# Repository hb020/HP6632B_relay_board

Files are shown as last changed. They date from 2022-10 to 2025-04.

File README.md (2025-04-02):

HP 66332A and HP 6632B-6634B #760 Relay Option Board
===================
This repository contains the schematics for a PCB to mount a relay board in an HP 6632B (and siblings) power supply. It is an adaption of the original A6 PCB used in option #760 units.
This relay board allows 2 things:
- the use of these power supplies as a 4 quadrant "poor man's SMU" (but with relay glitches).
- to isolate the output. In some situations, like with a large capacitive load or a battery, it is possible to damage the PSU's crowbar circuit when switching the output off. This board allows the disconnection of the output terminals. 

It is not needed to recalibrate the device after installation, although it would not hurt.

Once installed, you will NOT see the option appear when requesting `*OPT?` via the control interface (RS232/GPIB) (at least not on firmware 1.03). You will now however be able to use the relay control options in the front panel menu (under Output), or via `OUTPout`, `OUTPut:RELay`, and `OUTPut:RELay:POLarity`.

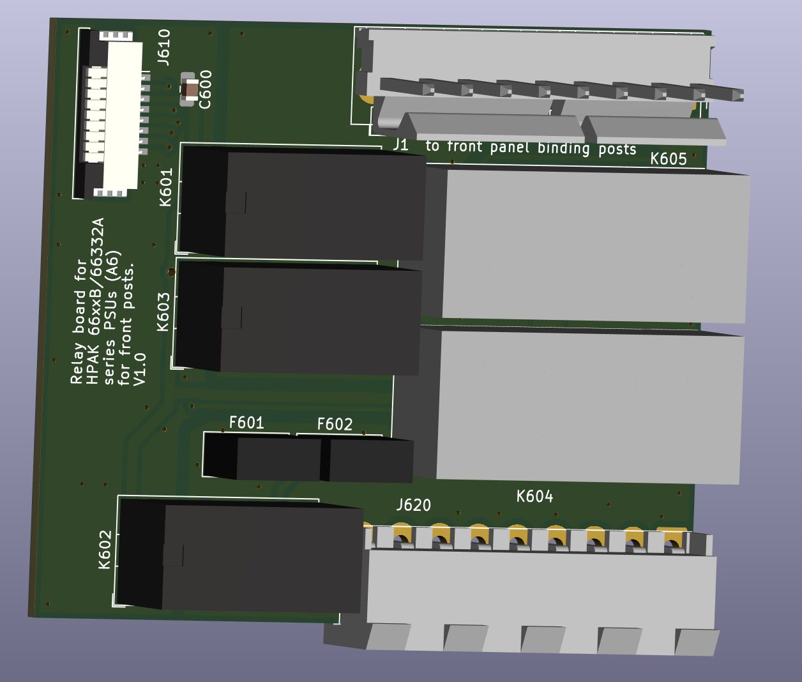
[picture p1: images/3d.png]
Circuit board


In contrast to the original option #760 PCB, this board:
- is meant to be used with front binding posts. See [option 020 board](https://github.com/hb020/HP6632B_binding_posts). If you want to use it with the standard backside terminals: just add 4 connections from the top connector to the bottom connector, according to the original schema that can be found in the service manual (the relevant extract can be found [here](doc/66332A%20Service%20Manual_9018-01125_extract.pdf)).
- has other minor changes like swapping the ports on the driver IC and allowing the use of standard series resistors (at least, the series that I had). 
- makes no use of the MP23/06612-00005 "Relay Option Bracket", which you will likely not have anyway if you do not already have the #760 board. The board is small enough and the weight distribution is such that this is not likely to be a problem.

For the component choice I took inspiration from "lukier" on [eevblog](https://www.eevblog.com/forum/repair/agilent-6632b-fault-repair-and-several-design-flaws/msg1019018/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). The main difference from his list was the FFC connectivity: 15cm is too short. I used molex 15267-0237: 20cm.

The components and layout chosen allow the board to be used on all variants of the HP 663xB family - even the 100 V 6634B.

The final result looks like this:
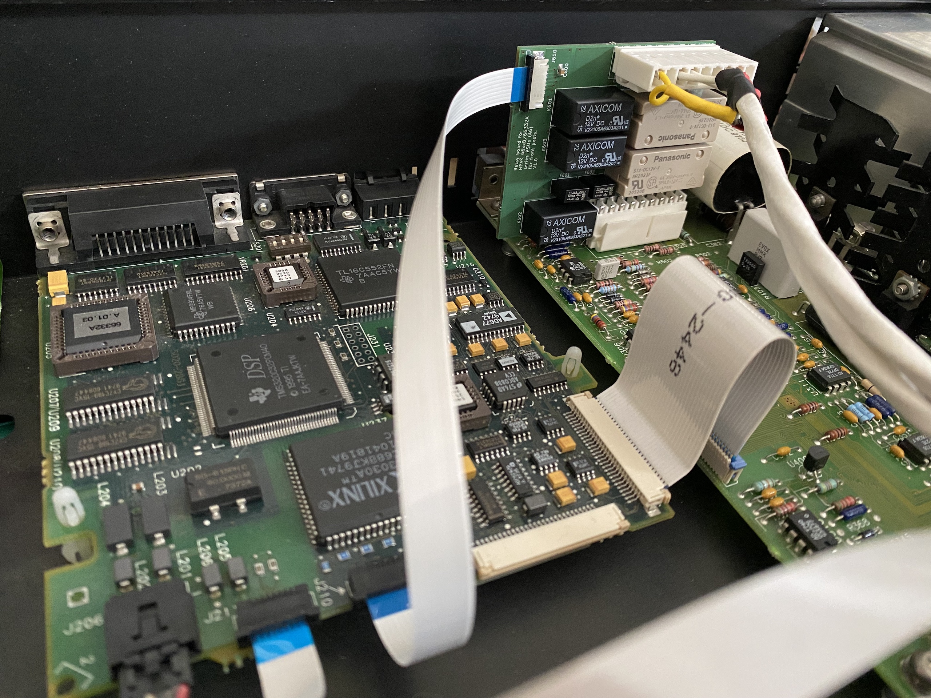
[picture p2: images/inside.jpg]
HP 66332A inside

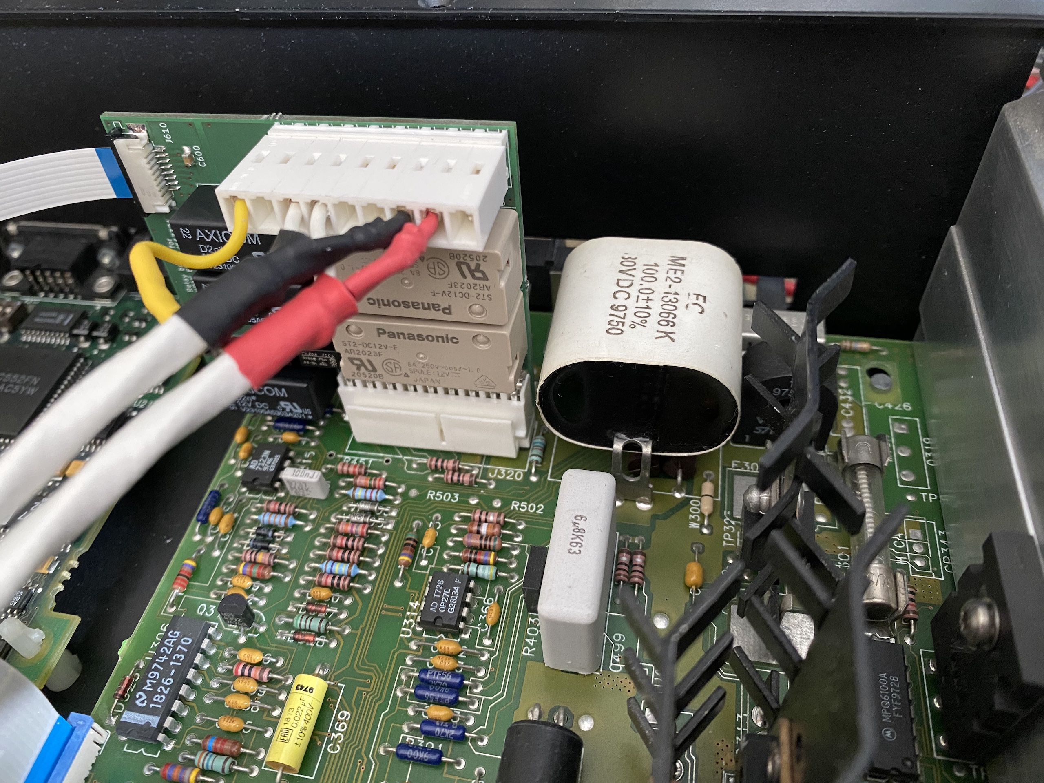
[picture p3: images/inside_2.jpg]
HP 66332A inside 2


Board behaviour
-----
This board keeps the sense lines functional, and I have not seen an impact on accuracy.
The sign of the voltage and current as measured (and set) does not change when you switch to "reverse" mode (the display still continues to show a positive voltage, although the voltage on the terminals is now negative).

During relay switching there are the inevitable delays and small artifacts.
Below is a switch from -1V (Reversed) to +1V (Normal), with a 1MΩ load. The switchover takes a little less than 80ms. 
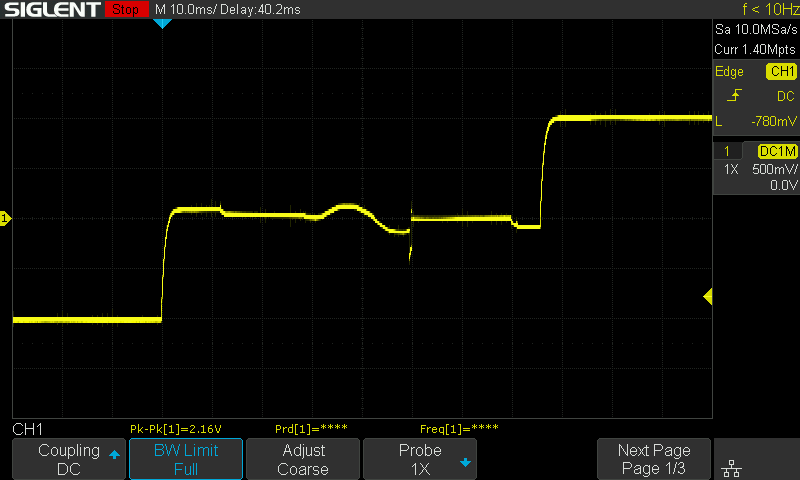
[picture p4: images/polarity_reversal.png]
polarity_reversal


The sine wave in the middle of the screen is 50Hz mains hum, as during that period the PSU output is disconnected. That hum, and the small spike that follows it, are largely suppressed when a load is applied.

About
-----
The root folder contains the KiCAD files. 
The gerber files can be found in the [/gerber](gerber/) folder.

Documentation of some of the components, and an extract of the service manual, with the original board drawings, can be found in the [/doc](doc/) folder. All files are publicly available on the respective manufacturers's websites, and are copied here for convenience. If this poses problems, let me know.

Related Repositories and info
--------------------

You may want to combine this with the [option 020 Frontpanel Binding Posts](https://github.com/hb020/HP6632B_binding_posts).

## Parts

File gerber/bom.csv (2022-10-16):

Designator | Footprint | Quantity | Value | LCSC Part #
C1, C600 | C_0805_2012Metric_Pad1.18x1.45mm_HandSolder | 2 | 100nF 25V
F601, F602 | Fuse_Littelfuse_395Series | 2 | Bussmann SS-5H-1.25A-APH
J1 | Molex_KK-396_A-41791-0009_1x09_P3.96mm_Vertical | 1 | Molex 26-60-4090 (KK396)
J610 | TE_84953-8_1x08-1MP_P1.0mm_Horizontal | 1 | 68610814422 8 pos 1mm FFC
J620 | Molex_KK-396_A-41815-0009_1x09_P3.96mm_Horizontal | 1 | Molex 09-48-1094 or 09-48-3095
K601, K602, K603 | Relay_DPDT_Omron_G5V-2 | 3 | V23105-A5303-A201
K604, K605 | Relay_Panasonic_ST2-F | 2 | ST2-DC12V-F
R1, R3, R5 | R_1206_3216Metric_Pad1.30x1.75mm_HandSolder | 3 | 75
R601, R602 | R_1206_3216Metric_Pad1.30x1.75mm_HandSolder | 2 | 220 0.5W
R603, R605, R607 | R_1206_3216Metric_Pad1.30x1.75mm_HandSolder | 3 | 100
R604, R606 | R_1206_3216Metric_Pad1.30x1.75mm_HandSolder | 2 | 150
U601 | SOIC-16_3.9x9.9mm_P1.27mm | 1 | NCV1413B

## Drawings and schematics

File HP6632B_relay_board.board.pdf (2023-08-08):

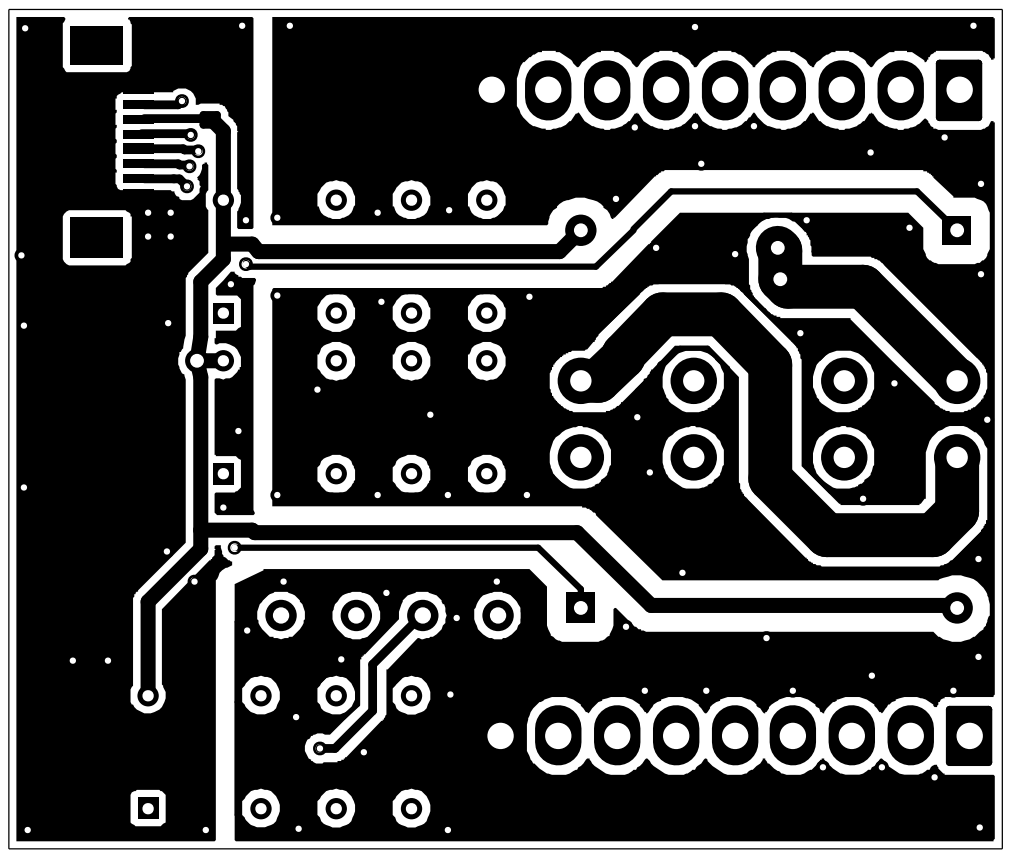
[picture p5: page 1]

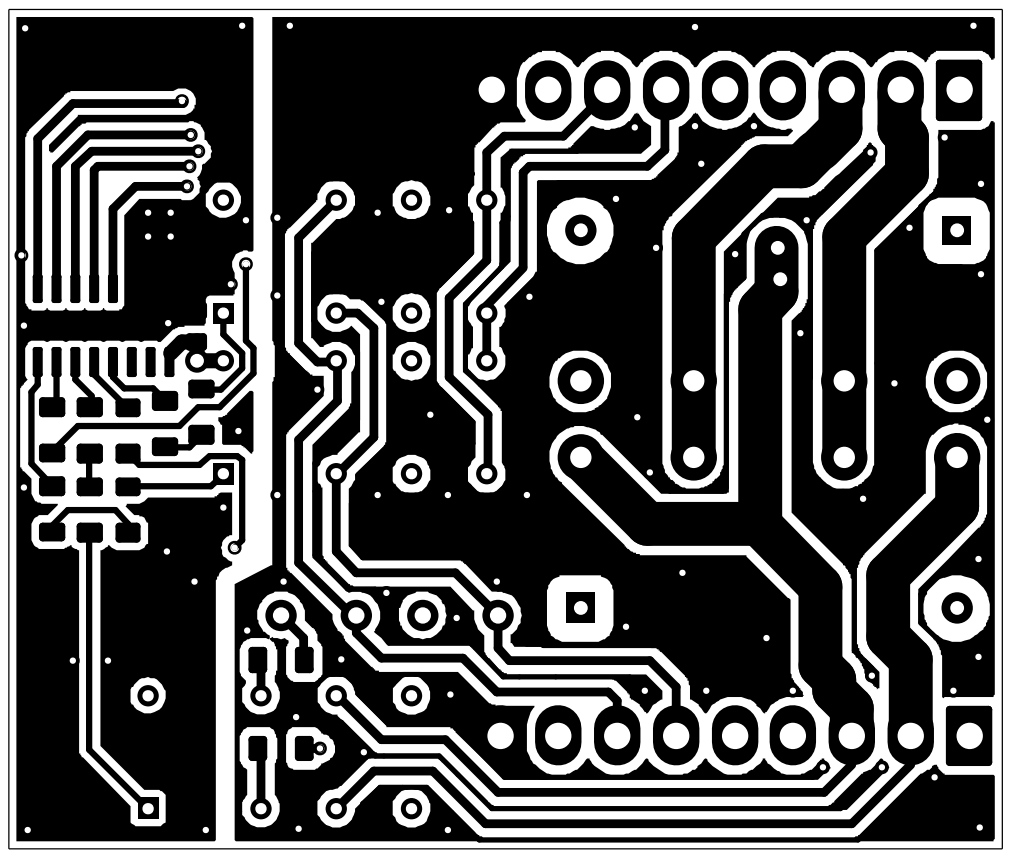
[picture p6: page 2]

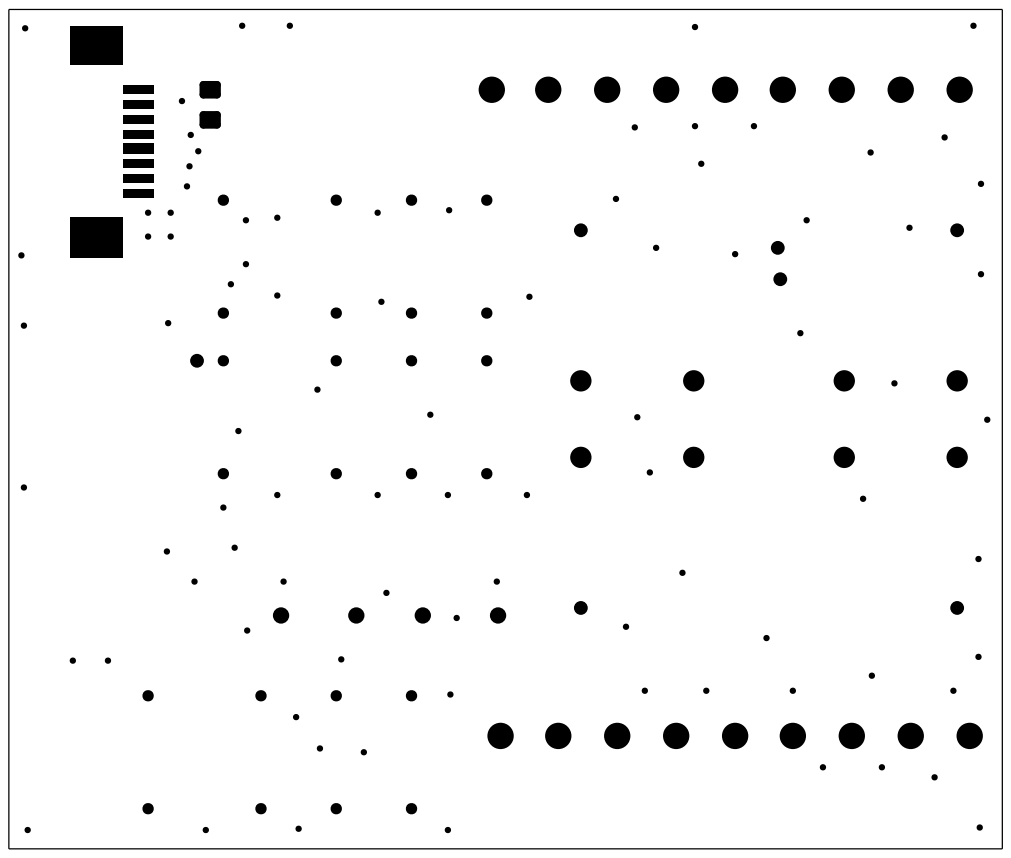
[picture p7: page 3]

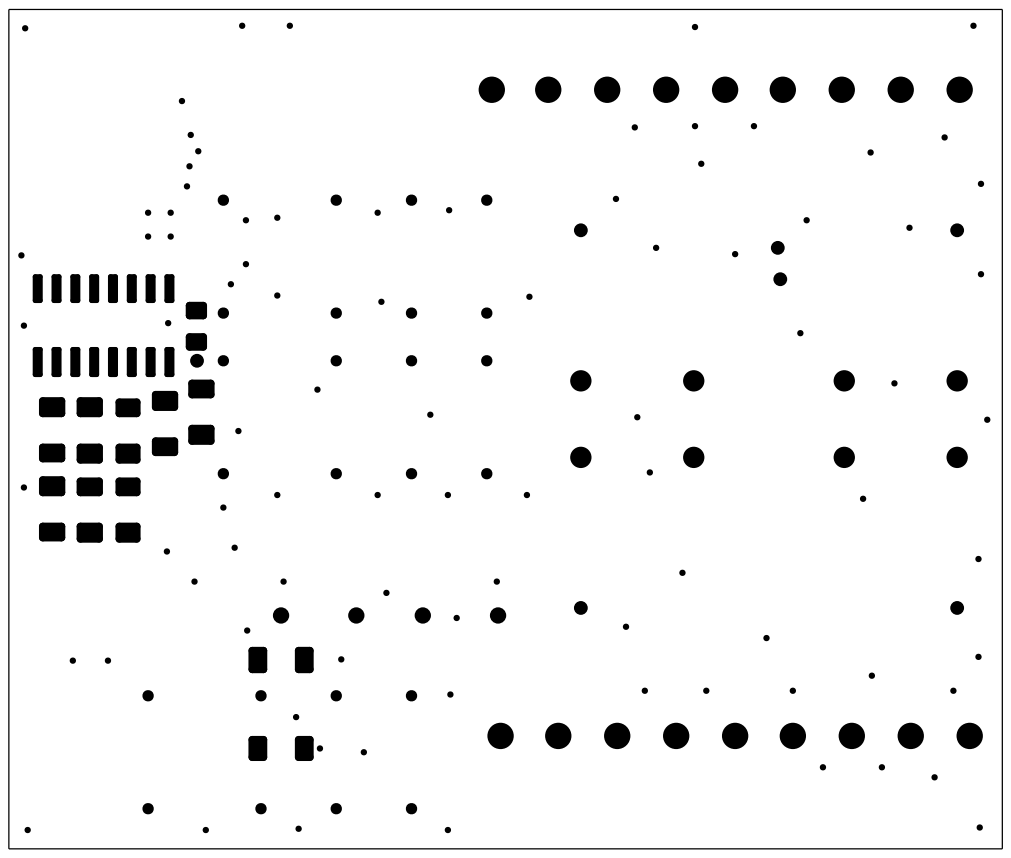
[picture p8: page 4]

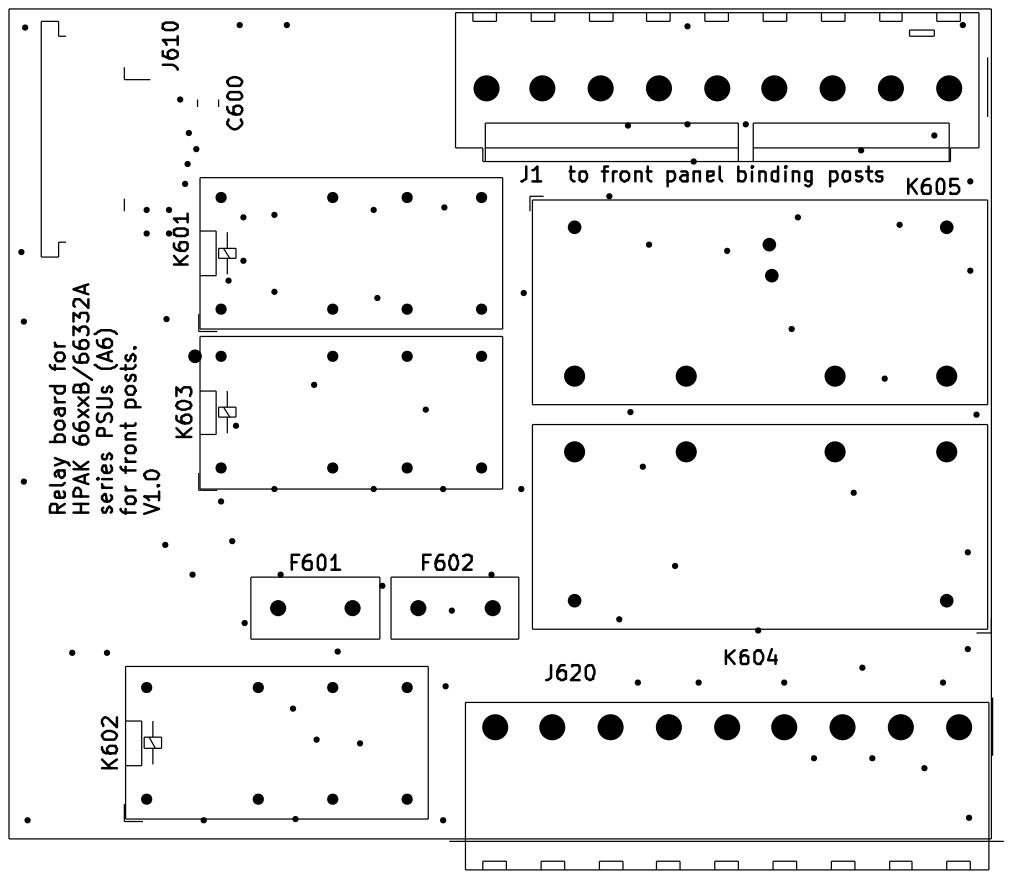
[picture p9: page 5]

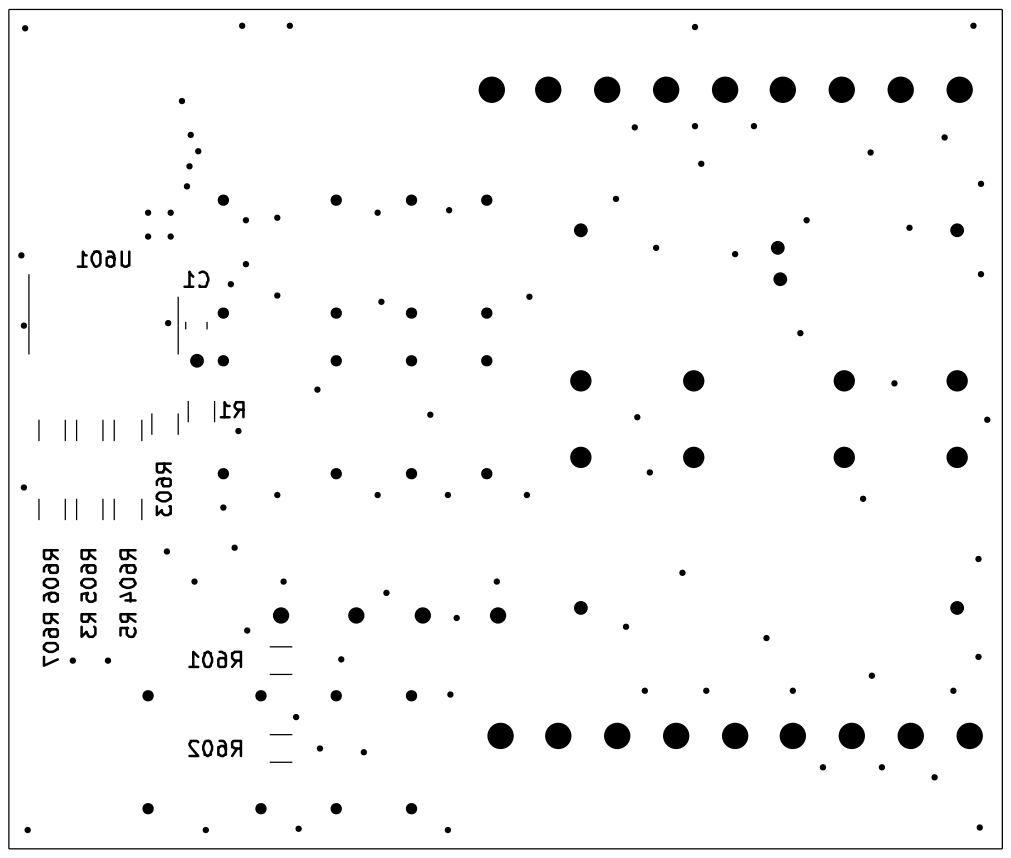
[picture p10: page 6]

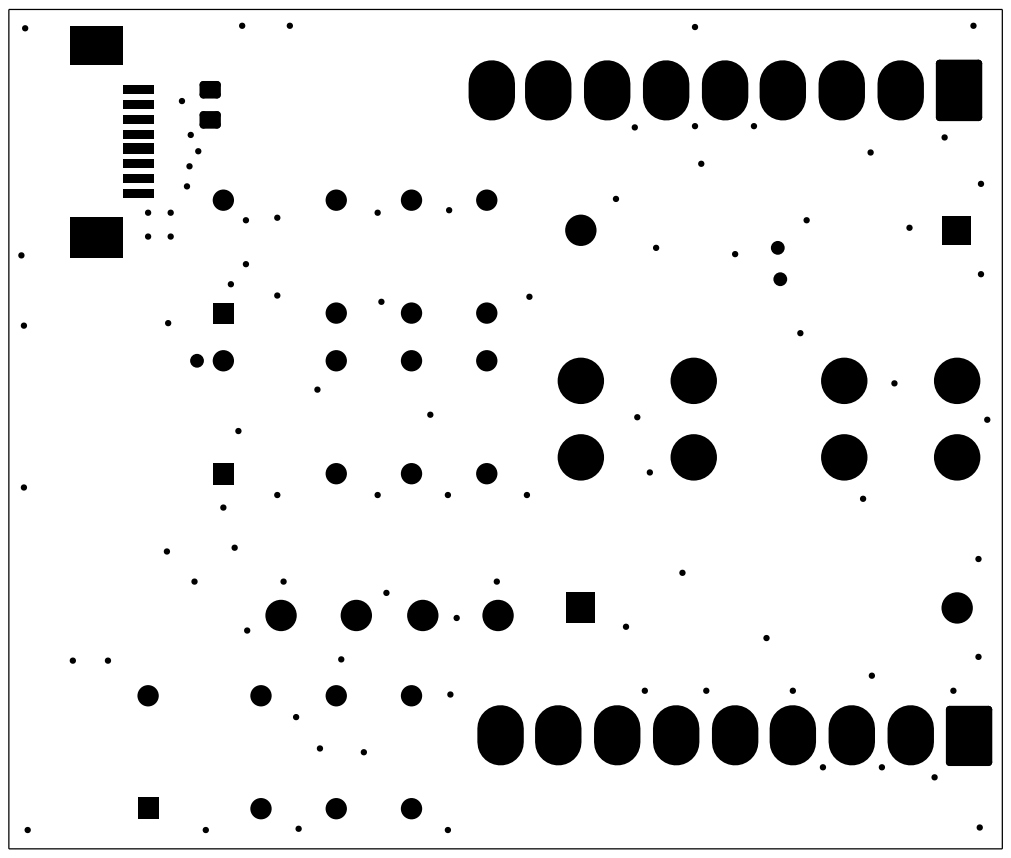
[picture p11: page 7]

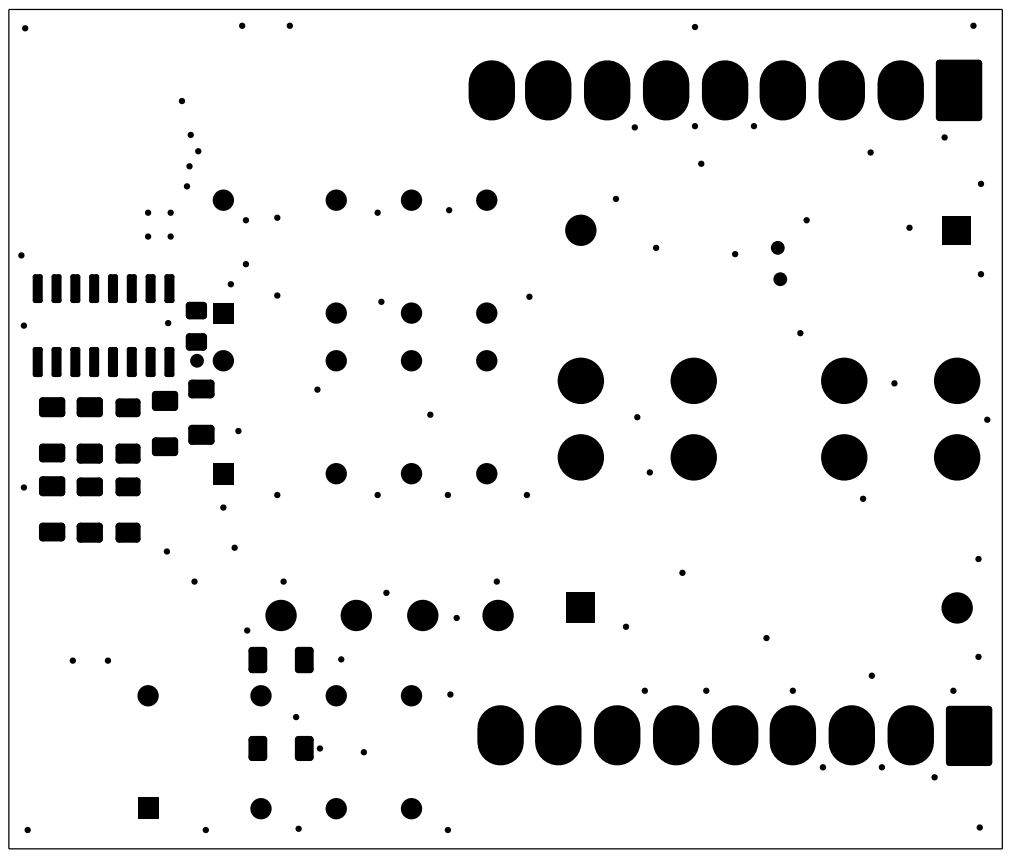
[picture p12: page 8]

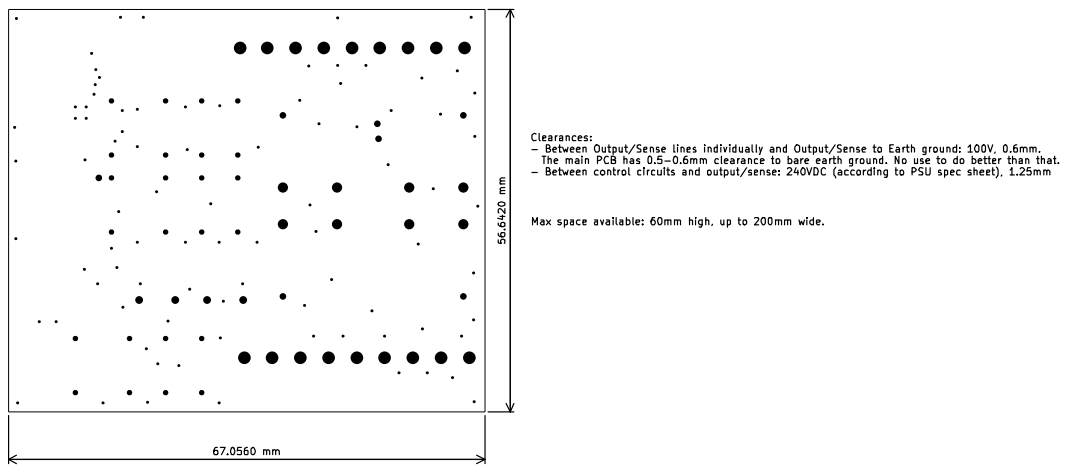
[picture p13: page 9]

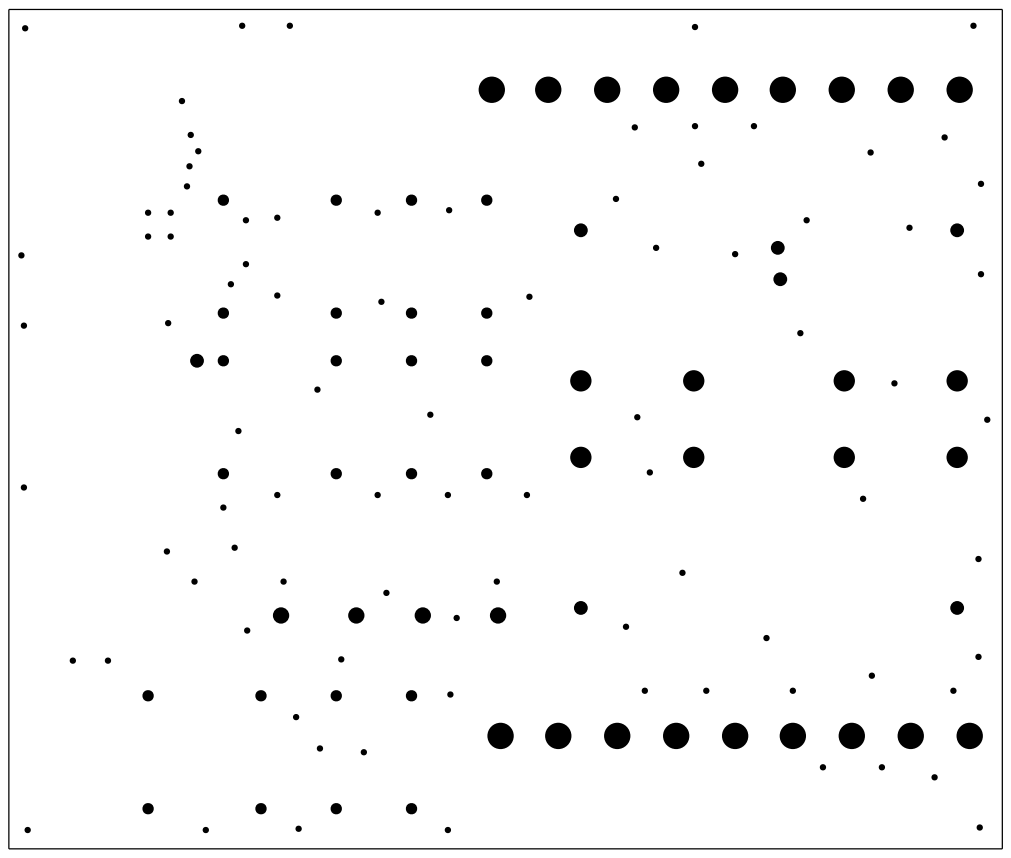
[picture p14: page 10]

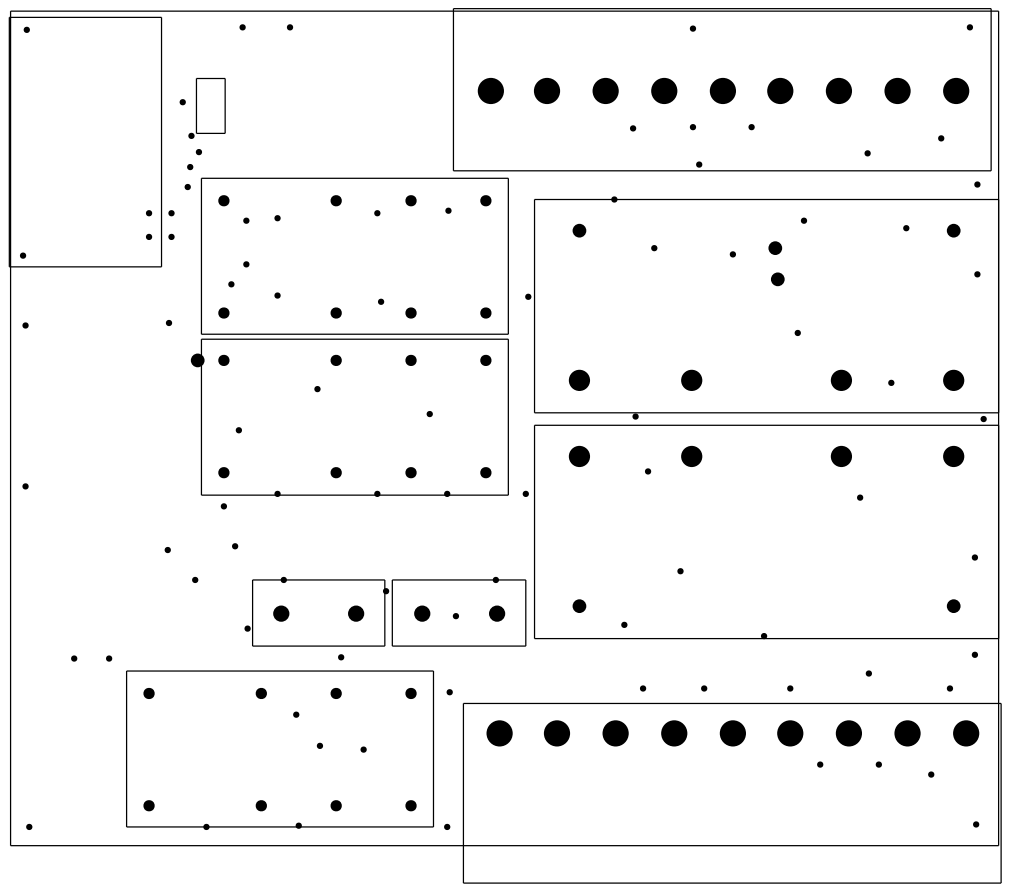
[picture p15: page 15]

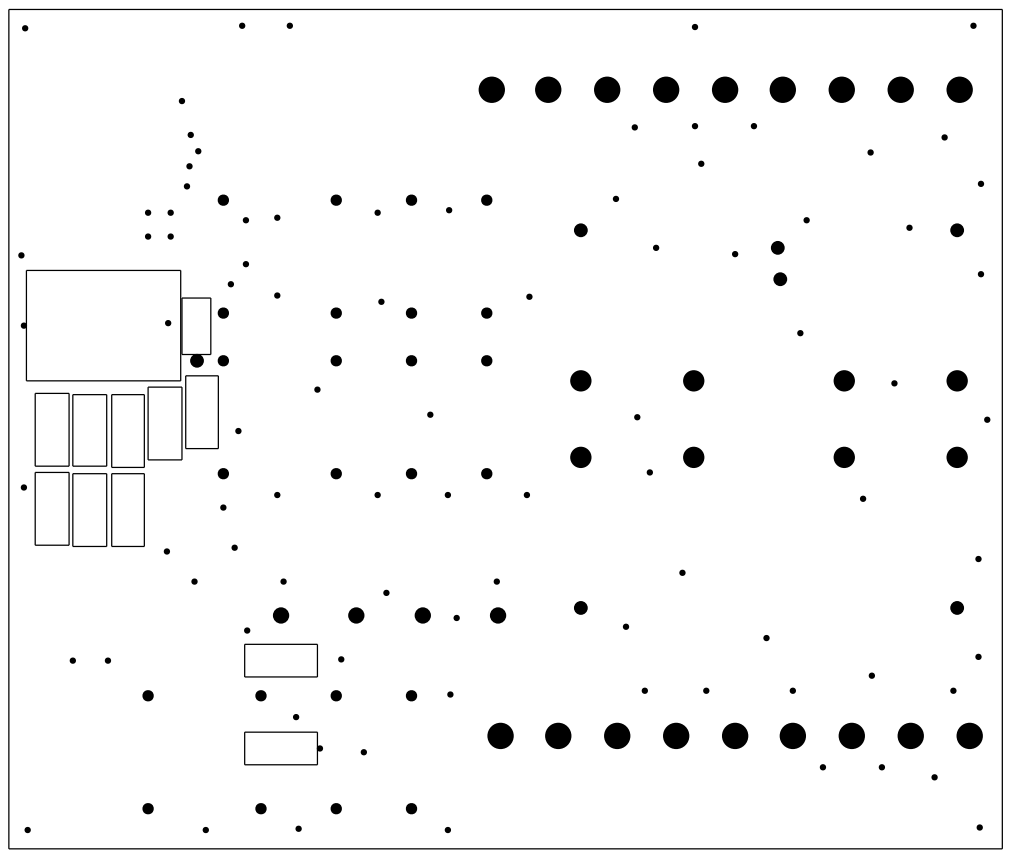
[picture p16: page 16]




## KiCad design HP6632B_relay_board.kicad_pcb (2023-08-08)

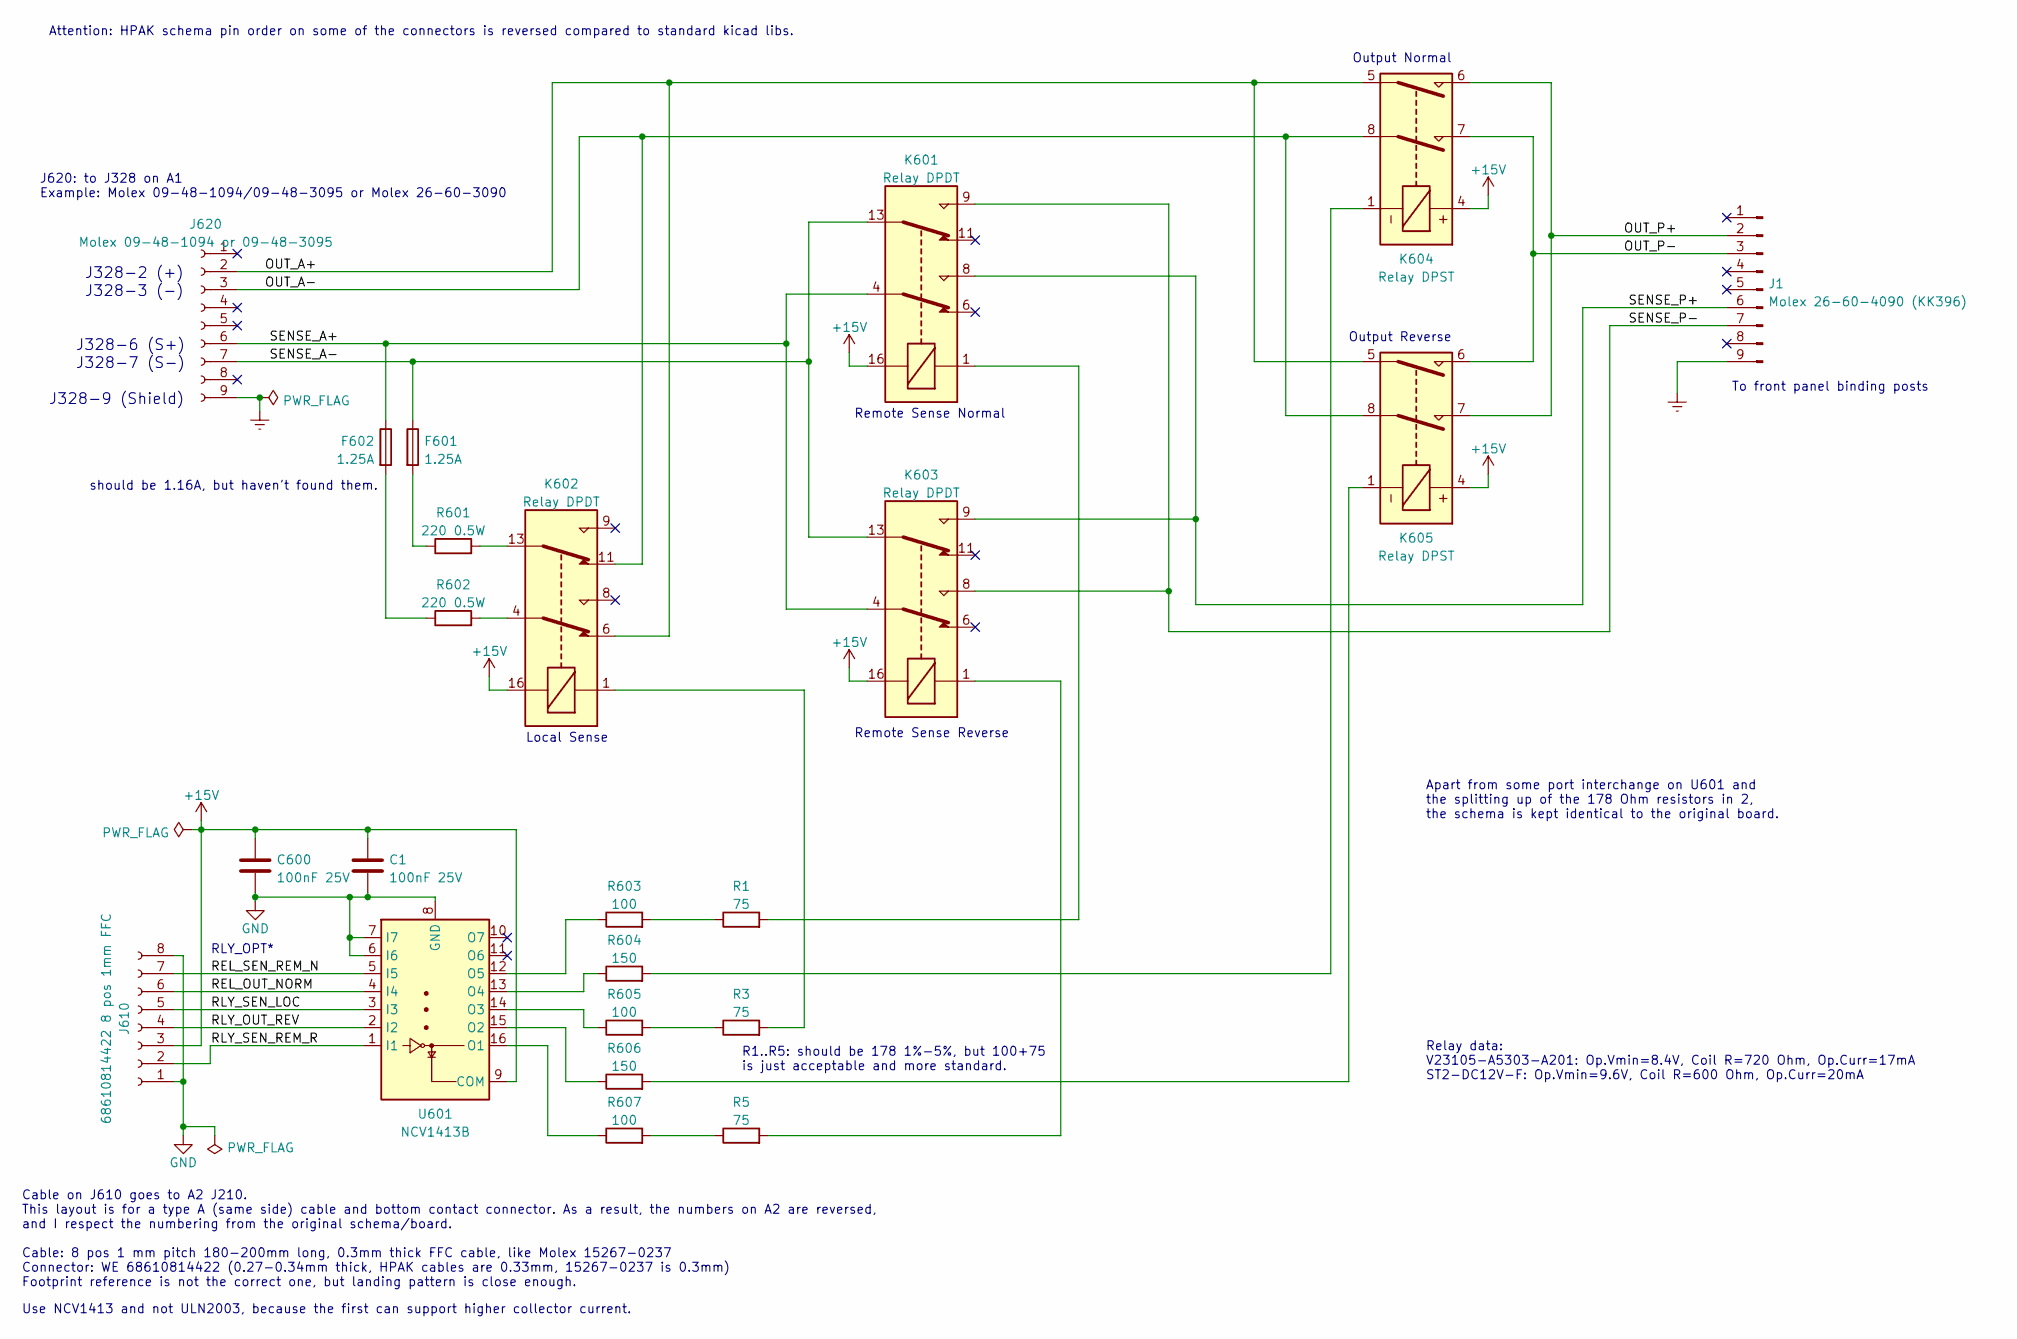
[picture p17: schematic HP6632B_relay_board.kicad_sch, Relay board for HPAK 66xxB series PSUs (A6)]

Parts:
C1, C600: 100nF 25V; C_0805_2012Metric_Pad1.18x1.45mm_HandSolder
F601, F602: 1.25A; Fuse_Littelfuse_395Series
J1: Molex 26-60-4090 (KK396); Molex_KK-396_A-41791-0009_1x09_P3.96mm_Vertical
J610: 68610814422 8 pos 1mm FFC; TE_84953-8_1x08-1MP_P1.0mm_Horizontal
J620: Molex 09-48-1094 or 09-48-3095; Molex_KK-396_A-41815-0009_1x09_P3.96mm_Horizontal
K601, K602, K603: Relay DPDT; Relay_DPDT_Omron_G5V-2
K604, K605: Relay DPST; Relay_Panasonic_ST2-F
R1, R3, R5: 75; R_1206_3216Metric_Pad1.30x1.75mm_HandSolder
R601, R602: 220 0.5W; R_1206_3216Metric_Pad1.30x1.75mm_HandSolder
R603, R605, R607: 100; R_1206_3216Metric_Pad1.30x1.75mm_HandSolder
R604, R606: 150; R_1206_3216Metric_Pad1.30x1.75mm_HandSolder
U601: NCV1413B; SOIC-16_3.9x9.9mm_P1.27mm

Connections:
+15V: C1.1, C600.1, J610.3, K601.16, K602.16, K603.16, K604.4, K605.4, U601.9 (COM)
/OUT_A+: J620.2, K602.6, K604.5, K605.5
/OUT_A-: J620.3, K602.11, K604.8, K605.8
/OUT_P+: J1.2, K604.6, K605.7
/OUT_P-: J1.3, K604.7, K605.6
/REL_OUT_NORM: J610.6, U601.4 (I4)
/REL_SEN_REM_N: J610.7, U601.5 (I5)
/RLY_OUT_REV: J610.4, U601.2 (I2)
/RLY_SEN_LOC: J610.5, U601.3 (I3)
/RLY_SEN_REM_R: J610.2, U601.1 (I1)
/SENSE_A+: F602.1, J620.6, K601.4, K603.4
/SENSE_A-: F601.1, J620.7, K601.13, K603.13
/SENSE_P+: J1.6, K601.8, K603.9
/SENSE_P-: J1.7, K601.9, K603.8
Earth: J1.9, J620.9
GND: C1.2, C600.2, J610.1, J610.8, U601.6 (I6), U601.7 (I7), U601.8 (GND)
unnamed: F601.2, R601.1
unnamed: F602.2, R602.1
unnamed: K601.1, R1.2
unnamed: K602.1, R3.2
unnamed: K602.4, R602.2
unnamed: K602.13, R601.2
unnamed: K603.1, R5.2
unnamed: K604.1, R604.2
unnamed: K605.1, R606.2
unnamed: R1.1, R603.2
unnamed: R3.1, R605.2
unnamed: R5.1, R607.2
unnamed: R607.1, U601.16 (O1)
unnamed: R606.1, U601.15 (O2)
unnamed: R605.1, U601.14 (O3)
unnamed: R604.1, U601.13 (O4)
unnamed: R603.1, U601.12 (O5)

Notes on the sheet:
Use NCV1413 and not ULN2003, because the first can support higher collector current.
should be 1.16A, but haven't found them.
J328-2 (+)
Output Reverse
R1..R5: should be 178 1%-5%, but 100+75 is just acceptable and more standard.
RLY_OPT*
Attention: HPAK schema pin order on some of the connectors is reversed compared to standard kicad libs.
J328-3 (-)
J620: to J328 on A1 Example: Molex 09-48-1094/09-48-3095 or Molex 26-60-3090
J328-9 (Shield)
Relay data: V23105-A5303-A201: Op.Vmin=8.4V, Coil R=720 Ohm, Op.Curr=17mA ST2-DC12V-F: Op.Vmin=9.6V, Coil R=600 Ohm, Op.Curr=20mA
J328-6 (S+)
Remote Sense Reverse
Cable on J610 goes to A2 J210. This layout is for a type A (same side) cable and bottom contact connector. As a result, the numbers on A2 are reversed, and I respect the numbering from the original schema/board. Cable: 8 pos 1 mm pitch 180-200mm long, 0.3mm thick FFC cable, like Molex 15267-0237 Co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
J328-7 (S-)
Remote Sense Normal
Output Normal
To front panel binding posts
Local Sense
Apart from some port interchange on U601 and the splitting up of the 178 Ohm resistors in 2, the schema is kept identical to the original board.

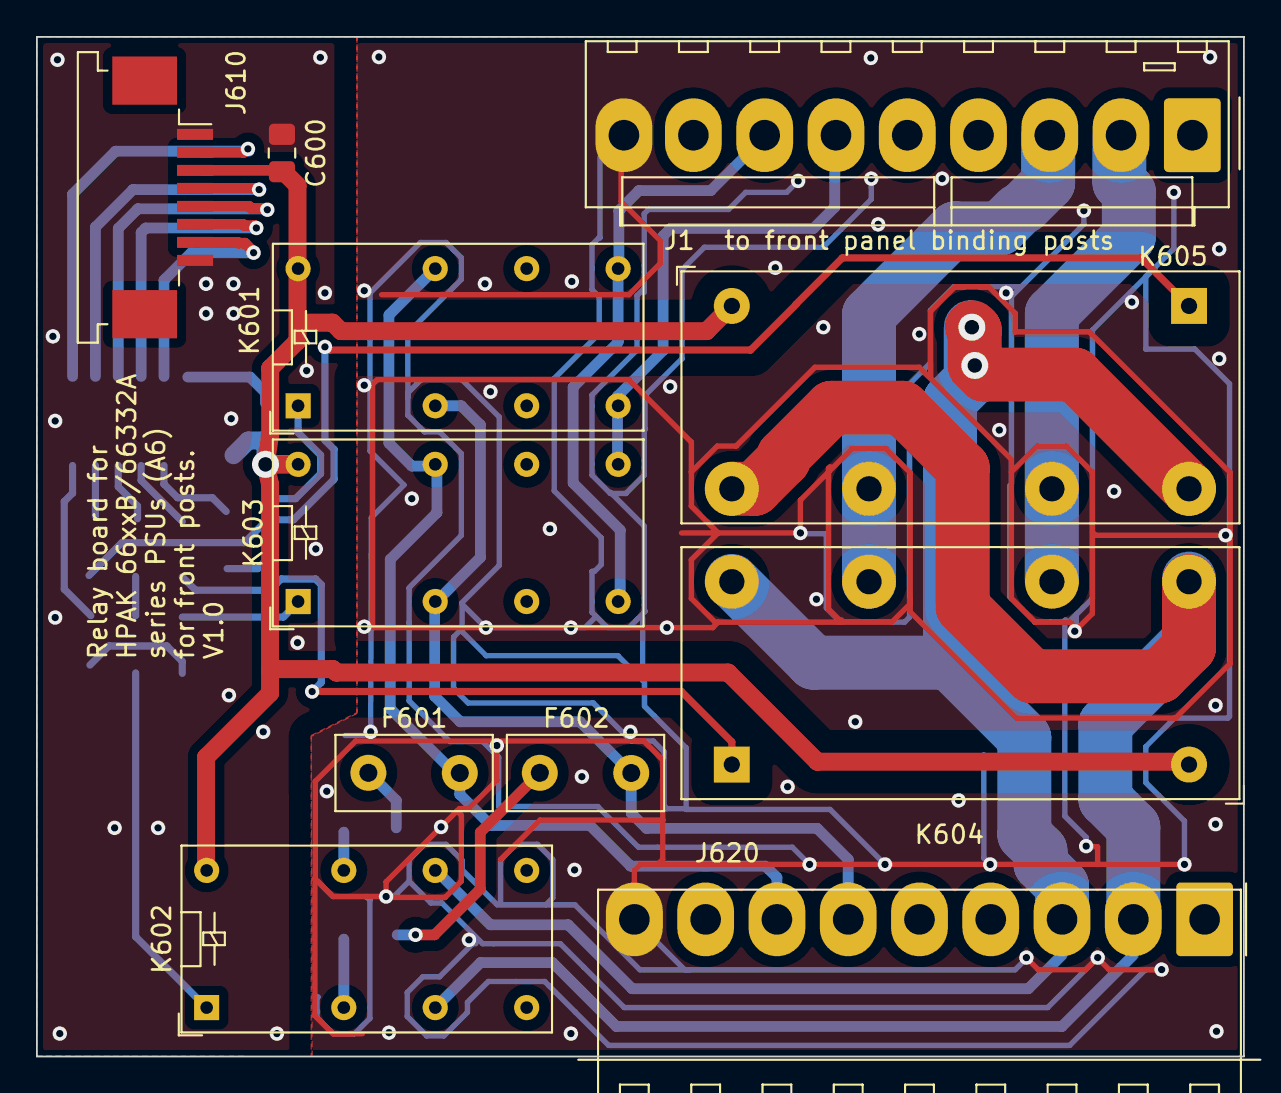
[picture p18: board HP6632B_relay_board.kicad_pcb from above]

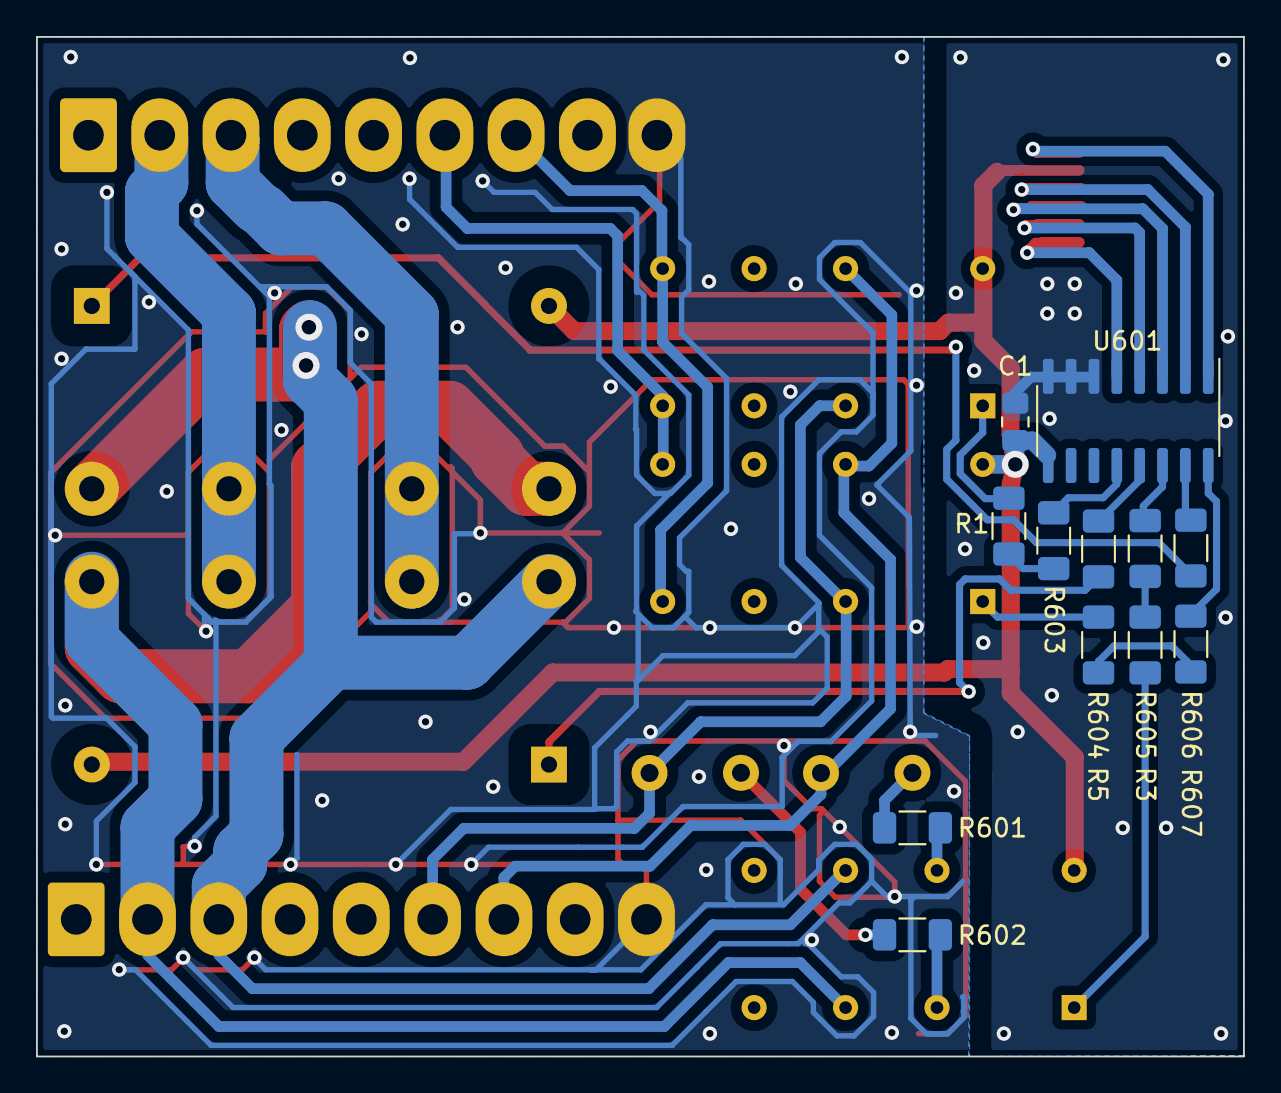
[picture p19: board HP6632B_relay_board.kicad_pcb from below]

Board: 2 copper layers, 67.1 x 56.6 mm, 23 parts (12 on the bottom side), 33 nets.

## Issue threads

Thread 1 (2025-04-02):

Missing Ribbon part number

pignoniG, 2025-04-02:
Hi, you mention that a 15cm ribbon is too short, do you remeber how long it should be? I cannot find the part number for that in the BOM.
these are two alternatives that i found in stock, but i'm not sure if the tikness is correct
[0152670237](https://www.digikey.it/en/products/detail/molex/0152670237/4427118)
[0152670241](https://www.digikey.it/en/products/detail/molex/0152670241/4427122)

Thanks!

hb020, 2025-04-02:
I used 15267-0237
Will add that in the description

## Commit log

2023-08-08 update to newer kicad version, added interactive BOM
    [HP6632B_relay_board.kicad_pcb, HP6632B_relay_board.kicad_sch]
2025-04-02 Update README.md, added FFC cable ref
